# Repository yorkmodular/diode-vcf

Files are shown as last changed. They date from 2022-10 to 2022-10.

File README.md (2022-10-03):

# Diode ladder VCF

Think of this as the bigger, uglier sibling of the MS20-style YAMS filter - it's bigger, badder, squallier and has voltage-controlled resonance too.

It also uses a lot of diodes (14 of them, to be precise)

This is a mostly through-hole build - the surface-mount LM13700 has been pre-soldered for your comfort and convenience.

## Files

You will find the following files here:

* `diode-vcf-schematic.png` - module schematic.
* `diode-vcf-BOM.xlsx` - BOM (Bill Of Materials)
* `diode-vcf-panel.fpd` and `diode-vcf-panel.dxf` - panel files; use these as a base if you wish to create your own, customised panel.

## Build Notes  

The build is relatively straightforward - the surface-mount LM13700 OTA has been pre-soldered. There are no wilfully weird components, but note the following:

* All diodes are 1N4148 or equivalent. Pay attention to their orientation before you solder them in place - the cathode (generally a black stripe) should correspond to the ring on the silkscreen.
* The paired transistors (Q1/Q5 and Q2/Q4) should be in contact with each other - you can either use a small zip-tie, thermal paste or glue for this. Matching the transistors isn't important, but if you want to do that then go nuts.
* The 'main' filter capacitors are C2-C4 - for best results, use polypropylene film caps; you could use ceramics in a pinch but you might need to get creative mounting them. Lower values will lead to 'sharper' resonance; lower than 33nF isn't recommended
* If you want to lessen the effect of the resonance controls, increase the values of R14 and R15 (200k is a good alternative value)
* There are two trimmers on the board - VOCT-TRIM1 controls the V/oct response of the exponential converter (Q1/Q3). CUT-TRIM1 is an offset for the cutoff CV; adjust this until you get a response you like. You probably want to be shooting for 0V at the base of Q1 with both the level and cut pots fully counterclockwise.
* All electrolytic capacitors are 10uF with the exception of C6 (150-220uF) - for best results, use 25V rated caps (50V will also work but these tend to be bulkier)
* All pots are 100k, linear taper.

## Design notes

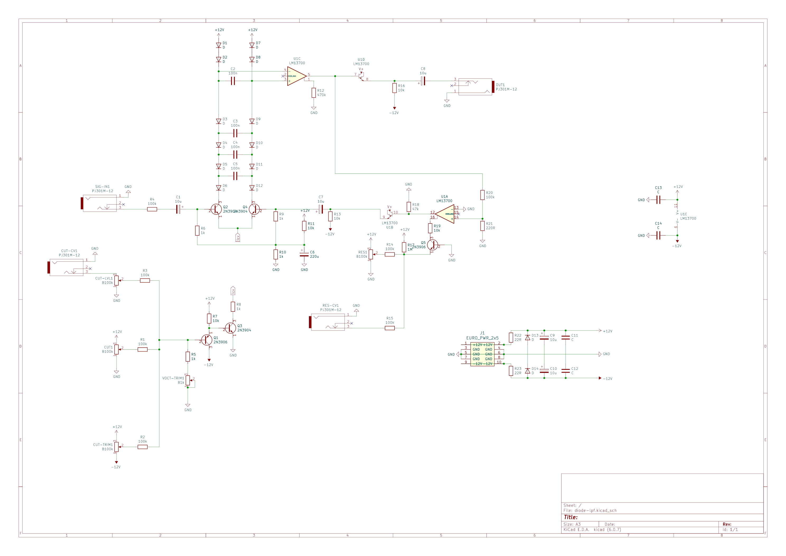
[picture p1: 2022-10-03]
diode-vcf-schematic.png

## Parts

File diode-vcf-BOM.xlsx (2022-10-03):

Ref | Qnty | Value | Description
C1, C7, C8, C9, C10, | 5 | 10u | Electrolytic capacitor, 25V
C2, C3, C4, C5, | 4 | 100n | Polypropylene film capacitor
C6, | 1 | 220u | Electrolytic capacitor, 25V
C11, C12, C13, C14, | 4 | 100n | Unpolarized capacitor
CUT1, | 1 | B100k | Alpha 9mm vertical pot – linear taper
CUT-CV1, | 1 | PJ301M-12 | 3.5mm jack – cutoff CV in
CUT-LVL1, | 1 | B100k | Alpha 9mm vertical pot – linear taper
CUT-TRIM1, | 1 | B100k | Alpha 9mm vertical pot – linear taper
D1, D2, D3, D4, D5, D6, D7, D8, D9, D10, D11, D12, D13, D14, | 14 | 1N4148 | Diode – 1N4148 or equivalent
J1, | 1 | EURO_PWR_2x5 | 2x5mm pin header, 2.54mm centres – stripe is -12V rail
OUT1, | 1 | PJ301M-12 | 3.5mm jack – signal out
Q1, Q5, | 2 | 2N3906 | -0.2A Ic, -40V Vce, Small Signal PNP Transistor, TO-92
Q2, Q3, Q4, | 3 | 2N3904 | 0.2A Ic, 40V Vce, Small Signal NPN Transistor, TO-92
R1, R2, R3, R4, R14, R15, R20, | 7 | 100k | Resistor
R5, R6, R8, R9, R10, | 5 | 1k | Resistor
R7, R11, R13, R16, R19, | 5 | 10k | Resistor
R12, | 1 | 470k | Resistor
R17, | 1 | 1M | Resistor
R18, | 1 | 47k | Resistor
R21, | 1 | 220R | Resistor
R22, R23, | 2 | 22R | Resistor
RES1, | 1 | B100k | Alpha 9mm vertical pot – linear taper
RES-CV1, | 1 | PJ301M-12 | 3.5mm jack – resonance CV in
SIG-IN1, | 1 | PJ301M-12 | 3.5mm jack – signal in
U1, | 1 | LM13700 | Dual Operational Transconductance Amplifiers with Linearizing Diodes and Buffers, DIP-16/SOIC-16
VOCT-TRIM1, | 1 | B1k

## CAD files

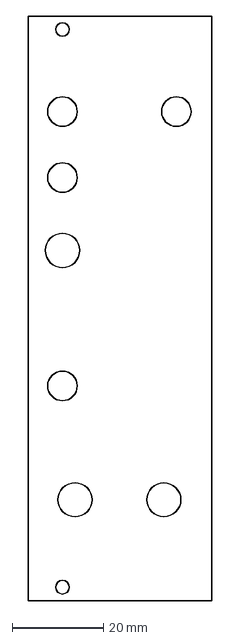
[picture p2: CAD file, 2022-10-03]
diode-vcf-panel.dxf
40.3 x 128.4 mm
